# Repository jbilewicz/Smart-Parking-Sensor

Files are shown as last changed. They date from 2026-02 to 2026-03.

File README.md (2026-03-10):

#  Smart Parking Sensor

## 📝 Project Overview
This is an advanced parking assistance system designed as a mechatronic project. It combines high-accuracy ultrasonic distance sensing with a smooth graphical interface.

The system features an **Exponential Moving Average (EMA)** filter to eliminate sensor noise and a **Fast Response** algorithm for immediate emergency detection.

##  Tech Stack
<p align="left">
  
  
  
  
</p>

---

##  Components Used
- **Microcontroller:** ESP32 (DEVKITV1).
- **Distance Sensor:** HC-SR04 Ultrasonic module.
- **Display:** SSD1306 128x64 OLED (I2C) for real-time bar animation.
- **Indicators:**
  - 🟢 **Green LED:** Safe distance (>30cm).
  - 🟡 **Yellow LED:** Caution (20-30cm).
  - 🔴 **Red LED:** Danger (<20cm).
- **Audio:** Active Buzzer (**F/CM12P**) with dynamic frequency.
- **Control:** Hardware **Mute Button** for sound toggling.

---

##  Hardware Design
The PCB was designed in **Autodesk EAGLE** with a focus on durability and clean layout:
- **Board Dimensions:** 180 x 70 mm.
- **Mounting:** 4x 3.2mm symmetric holes for M3 screws.
- **Layout:** Optimized 2.54mm grid for prototyping consistency.

###  Pinout Table
| Component | Pin | Note |
| :--- | :--- | :--- |
| **HC-SR04 Trig** | GPIO 5 | Output Trigger |
| **HC-SR04 Echo** | GPIO 18 | Input Echo |
| **OLED SDA** | GPIO 21 | I2C Data |
| **OLED SCL** | GPIO 22 | I2C Clock |
| **Buzzer (+)** | GPIO 27 | PWM Tone Control |
| **Mute Button** | GPIO 4 | Internal Pull-up |
| **LEDs (G, Y, R)**| 13, 12, 14 | Digital Indicators |

---

##  Software Logic
The firmware includes:
1. **Signal Smoothing:** Prevents the progress bar from flickering using software-based EMA.
2. **Fast Response:** Instantly updates if the distance changes by >15cm to handle rapid movements.
3. **Dynamic Beeping:** The closer the object, the higher the tone and shorter the delay.

---

##  Repository Structure
- `/Firmware` - Arduino source code (.ino).
- `/Hardware` - EAGLE schematic (.sch) and board (.brd) files.
- `/Exports` - Visualizations, PDF schematics, and PCB renders.

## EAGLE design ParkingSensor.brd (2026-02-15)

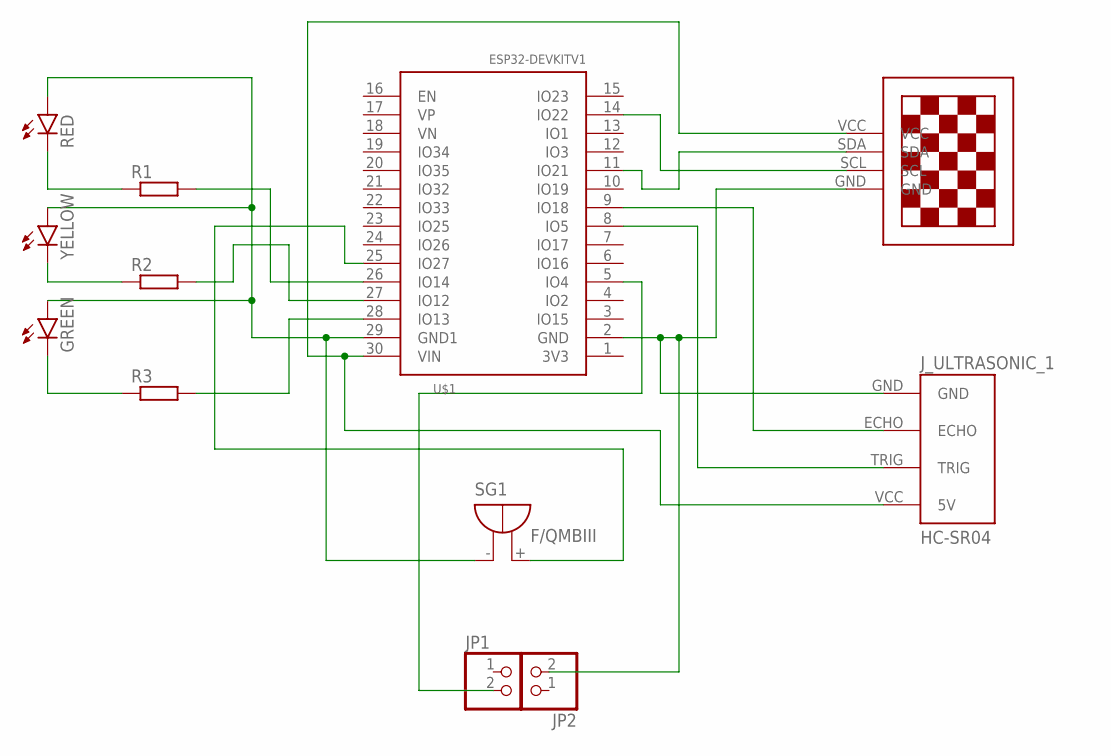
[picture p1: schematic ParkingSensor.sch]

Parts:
GREEN: LED5MM
JP1, JP2: PINHD-1X2; 1X02
J_ULTRASONIC_1: HC-SR04; HC-SR04_FOOTPRINT
R1, R2, R3: R-EU_0204/7; 0204/7
RED: LED5MM
SG1: F/QMBIII
U$1: ESP32DEVKITV1; ESP32-DEVKITV1
U$3: 13"OLED13"OLED; 1.3"OLED
YELLOW: LED5MM

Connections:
unnamed: JP2.2, J_ULTRASONIC_1.GND, U$1.2 (GND), U$3.GND
unnamed: J_ULTRASONIC_1.VCC (5V), U$1.30 (VIN), U$3.VCC
unnamed: U$1.14 (IO22), U$3.SCL
unnamed: U$1.11 (IO21), U$3.SDA
unnamed: SG1.+ (-), U$1.25 (IO27)
unnamed: J_ULTRASONIC_1.TRIG, U$1.8 (IO5)
unnamed: J_ULTRASONIC_1.ECHO, U$1.9 (IO18)
unnamed: GREEN.K (C), R3.1
unnamed: R2.1, YELLOW.K (C)
unnamed: R1.1, RED.K (C)
unnamed: R1.2, U$1.26 (IO14)
unnamed: R2.2, U$1.27 (IO12)
unnamed: R3.2, U$1.28 (IO13)
unnamed: GREEN.A, RED.A, SG1.- (+), U$1.29 (GND1), YELLOW.A
unnamed: JP1.2, U$1.5 (IO4)

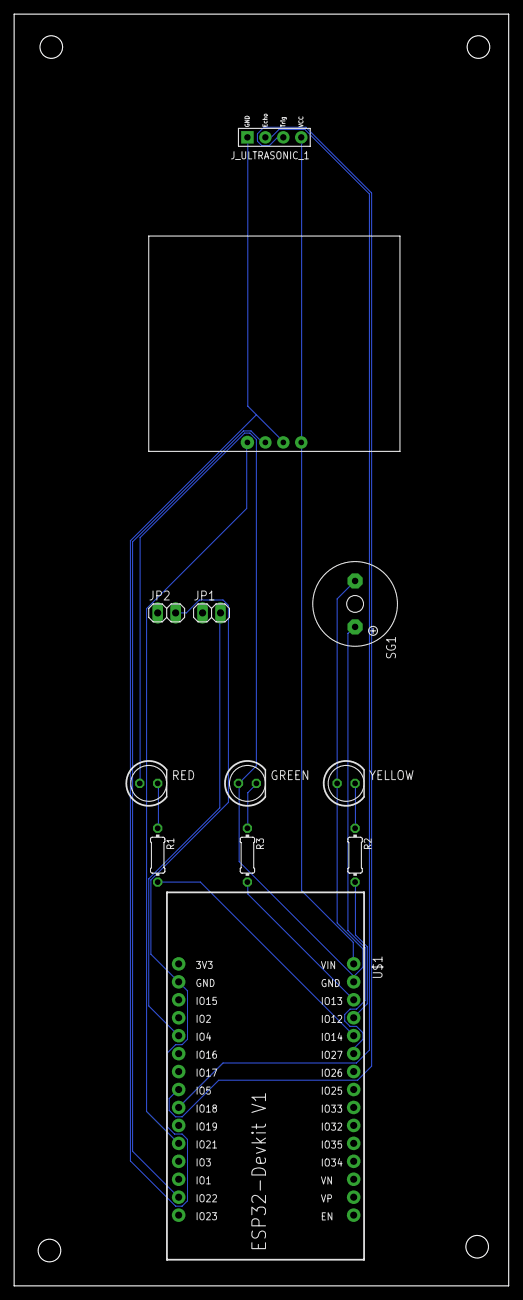
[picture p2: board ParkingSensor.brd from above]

Board: 2 copper layers, 70.0 x 180.0 mm, 12 parts (0 on the bottom side), 15 nets.

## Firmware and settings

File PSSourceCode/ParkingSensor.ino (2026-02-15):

#include <Wire.h>
#include <Adafruit_GFX.h>
#include <Adafruit_SSD1306.h>

#define SCREEN_WIDTH 128
#define SCREEN_HEIGHT 64
Adafruit_SSD1306 display(SCREEN_WIDTH, SCREEN_HEIGHT, &Wire, -1);

const int trigPin = 5;
const int echoPin = 18;
const int ledGreen = 13;
const int ledYellow = 12;
const int ledRed = 14;
const int buzzer = 27;
const int buttonPin = 4;

#define SOUND_SPEED 0.034
#define MAX_DIST 50.0

float smoothDistance = 50.0;
float filterCoeff = 0.15;  

bool isMuted = false;
bool lastButtonState = HIGH;

void setup() {
    Serial.begin(115200);
    pinMode(trigPin, OUTPUT);
    pinMode(echoPin, INPUT);
    pinMode(ledGreen, OUTPUT);
    pinMode(ledYellow, OUTPUT);
    pinMode(ledRed, OUTPUT);
    pinMode(buzzer, OUTPUT);
    pinMode(buttonPin, INPUT_PULLUP);

    if (!display.begin(SSD1306_SWITCHCAPVCC, 0x3C)) {
        for (;;);
     
  }
    display.clearDisplay();
    display.setTextColor(WHITE);
}

void loop() {
  bool currentButtonState = digitalRead(buttonPin);
    if (currentButtonState == LOW && lastButtonState == HIGH) {
        isMuted = !isMuted;
        delay(50);
     
  }
    lastButtonState = currentButtonState;

  digitalWrite(trigPin, LOW);
    delayMicroseconds(2);
    digitalWrite(trigPin, HIGH);
    delayMicroseconds(10);
    digitalWrite(trigPin, LOW);
    
  long duration = pulseIn(echoPin, HIGH, 30000);
    float currentDist = duration * SOUND_SPEED / 2.0;

  if (currentDist > 0 && currentDist < 200) {
    if (abs(currentDist - smoothDistance) > 15) {
            smoothDistance = currentDist;
         
    }
    else {
      smoothDistance = smoothDistance + (currentDist - smoothDistance) * filterCoeff;
         
    }
     
  }

    int displayDist = (int)(smoothDistance + 0.5);

  digitalWrite(ledGreen, LOW);
    digitalWrite(ledYellow, LOW);
    digitalWrite(ledRed, LOW);

    if (displayDist > 30) {
        digitalWrite(ledGreen, HIGH);
        noTone(buzzer);
     
  }
    else if (displayDist <= 30 && displayDist > 19) {
        digitalWrite(ledYellow, HIGH);
        if (!isMuted) {
            tone(buzzer, 800);
            delay(40); 
            noTone(buzzer);
         
    }
        int gap = map(displayDist, 19, 30, 80, 250);
        delay(gap);
     
  }
    else if (displayDist <= 19 && displayDist > 6) {
        digitalWrite(ledRed, HIGH);
        if (!isMuted) {
            tone(buzzer, 1300);
            delay(30);
            noTone(buzzer);
         
    }
        int gap = map(displayDist, 6, 19, 10, 80);
        delay(gap);
     
  }
    else if (displayDist <= 6 && displayDist > 0) {
        digitalWrite(ledRed, HIGH);
        if (!isMuted) tone(buzzer, 2500);
        else noTone(buzzer);
     
  }


  display.clearDisplay();
    
  float barWidth = map(constrain(smoothDistance, 0, MAX_DIST), 0, MAX_DIST, 128, 0);
    display.drawRect(0, 0, 128, 12, WHITE);
       
  display.fillRect(0, 0, (int)barWidth, 12, WHITE);

    display.setTextSize(2);
    display.setCursor(0, 20);
    display.print("Dystans:");
    display.setCursor(20, 42);
    display.print(displayDist);
    display.print(" cm");

    display.setTextSize(1);
    display.setCursor(0, 56);
    if (isMuted) display.print("MUTE: ON");
    else display.print("MUTE: OFF");

    if (displayDist < 10) {
        display.setTextSize(2);
        display.setCursor(85, 42);
        display.print("!!!");
     
  }

    display.display();
}
